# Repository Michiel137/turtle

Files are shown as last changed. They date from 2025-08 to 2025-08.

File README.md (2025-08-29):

# Turtle Robot

Een rijdende robot gemaakt met 3D prints, goedkope onderdelen en geprogrammeerd in MicroPython.

Alle bestanden, inclusief deze beschrijving zijn op GitHub te vinden: https://github.com/Michiel137/turtle

## Start

De robot bevat alle bestanden die je nodig hebt, maar hij moet nog wel geconfigureerd worden om hem via WiFi te kunnen programmeren.

1. Sluit de robot met een USB kabel aan op de computer
1. Installeer de ontwikkelomgiving voor MicroPython: [Thonny](https://thonny.org/).
1. Open Thonny. Kies "Standard" voor "Initial Settings"
1. Klik rechtsonderin de statusbalk om de interpreter te configureren
1. Kies "MicroPython (Raspberry Pi Pico)" voor de interpreter
1. Kies "Board in FS mode @ COM..." voor de poort
1. Onderin de shell zie je nu een Python prompt. Je kan hier Python commando's uitvoeren
1. Open in Thonny het bestand boot.py van de robot: Bestand -> Open -> Raspberry Pi Pico -> boot.py
1. Haal van de laatste regel in het bestand de "#" weg en vervang \<SSID\> en \<PASSWORD\> met de WiFi netwerknaam en het WiFi wachtwoord
1. Sla het bestand op: Bestand -> Opslaan
1. Herstart de robot door op het Stop icoon te klikken (of Uitvoeren -> Stoppen/Opnieuw starten backend)
1. De robot maakt nu verbinding met het WiFi netwerk
1. In het shell scherm wordt het adres van de robot geprint achter "WebREPL server started on". Kopieer dit adres
1. Klik rechtsonderin de statusbalk om de interpreter te configureren: Selecteer "Configureren interpreter"
1. Vul bij "Port or WebREPL" het adres van de robot in, maar vervang "http://" door "ws://"
1. Vul voor het wachtwoord "geheim" in
1. OK
1. Thonny maakt nu verbinding via WiFi. De USB kabel is niet meer nodig
1. Op de robot staan een aantal scripts die je uit kan proberen: Bestand -> Open -> Raspberry Pi Pico
    - blink.py - klipper met de leds
    - noise.py - maak geluid
    - collision.py - rij rond en probeer botsingen te voorkomen
    - square.py - teken een vierkant
1. Nadat je het script geopend hebt kan je het met F5 uitvoeren (of Uitvoeren -> Voer huidige script uit)
1. Sommige scripts hebben geen einde. Je kan het script stoppen met Ctrl-C (of Uitvoeren -> Onderbreek uitvoering)
1. Probeer de scripts uit en pas ze aan!
1. Als je een idee hebt en een nieuw script wil maken, maak dan een nieuw bestand: Bestand -> Nieuw
    - Bestanden hoeven niet op de robot te staan om ze uit te voeren: Bestand -> Opslaan -> Deze computer
    - Het is een goed idee om voor een nieuw script te beginnen met een kopie van een bestaand script
    - als je een fout in het script hebt gemaakt wordt dat in het shell scherm getoond als je het script uitvoerd

## Problemen Oplossen

1. Zijn de batterijen leeg?
1. Als de verbinding van Thonny met de robot niet meer lijkt te werken, verbind dan opnieuw door rechtonderin de statusbalk te klikken en "MicroPython (Raspberry Pi Pico) ws://\<ip\>:8266" te kiezen

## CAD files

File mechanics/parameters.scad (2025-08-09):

/// Default chamfer.
chamfer = 0.4;

/// Layer height used for printing.
layer = 0.2;

thickness_chassis = 2.4;
thickness_nut = 2.4;


//
// Wheel
//

/// Diameter of wheel (rim + tire).
// diameter_wheel = 56;  // OSTR V3
diameter_wheel = 50.5;  // OSTR V2
radius_wheel = diameter_wheel / 2;

/// Size of o-ring used as tire.
diameter_tire = 3;
radius_tire = diameter_tire / 2;


//
// Motor
//

diameter_motor = 28;
radius_motor = diameter_motor / 2;
spacing_motor_mounts = 35;
/// Mounting height of the motor from the top of the chassis plate.
height_motor = 13.1;
/// The axle is offset from the mounting holes of the motor.
height_axle = height_motor - 8;


//
// Pen (Stabilo 88/32)
//

diameter_pen = 7.75;
radius_pen = diameter_pen / 2;
tolerance_pen = 0.05;

/// The positions of the pen aligner mounting holes.
positions_aligner_mounts = [[-12.5 / 2, +8 / 2], [+12.5 / 2, -8 / 2]];


//
// Electronics
//

/// The radius of the board corners.
/// \note The back mounting hole is at the center of the rounding radius.
rounding_board = 4;
/// The width of the board (side-to-side).
width_board = 52;
/// The length of the board (back-to-front).
length_board = 48;
/// The side-to-side distance of the board mounts.
width_board_mounts = width_board - 2 * rounding_board;
/// The back-to-front distance of the board mounts.
/// \note The board mounts are at the back corner, but not at the front corner.
length_board_mounts = 33;
/// positions of the board mounts with the board anchored at the back
positions_board_mounts = [
    [+width_board_mounts / 2, -rounding_board],
    [+width_board_mounts / 2, -rounding_board - length_board_mounts],
    [-width_board_mounts / 2, -rounding_board - length_board_mounts],
];

width_battery_holder = 33;


//
// quality
//

$fa = $preview ? 12 : 3;
$fs = $preview ? 2 : 0.2;
$overlap = 0.01;

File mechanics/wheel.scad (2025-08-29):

include <BOSL2/std.scad>

include <parameters.scad>

width_rim = 4;
width_disc = 2.5;
width_hub = 9;
diameter_hub = 11;
radius_hub = diameter_hub / 2;
radius_rim = radius_wheel - radius_tire;

rounding_wheel = 1;

module wheel() {
    difference() {
        up(width_disc)
        union() {
            difference() {
                down(width_disc - width_rim / 2)
                difference() {
                    cyl(r=radius_rim, h=width_rim, chamfer=chamfer);
                    // tire recess
                    torus(or=radius_wheel, r_min=radius_tire);
                }

                // disc
                radius_disc = radius_rim - 2 - 2 * chamfer;
                cyl(r=radius_disc, h=width_rim - width_disc, rounding1=rounding_wheel, chamfer2=-chamfer, extra2=$overlap, anchor=BOTTOM);

                // disc holes
                diameter_hole = radius_disc - radius_hub - 4 * rounding_wheel;
                radius_hole = diameter_hole / 2;
                zrot_copies(n=5)
                back((radius_disc + radius_hub) / 2)
                cyl(r=radius_hole, h=width_disc, rounding=-rounding_wheel, extra=$overlap, anchor=TOP);
            }

            // hub
            cyl(r=radius_hub, h=width_hub - width_disc, rounding1=-rounding_wheel, rounding2=rounding_wheel, extra1=$overlap, anchor=BOTTOM);
        }

        // shaft
        path = intersection([circle(d=5), rect([3, 10])])[0];
        offset_sweep(path, h=width_hub, ends=os_chamfer(-chamfer, extra=$overlap), anchor=BOTTOM);
        // shaft M3 set screw (only one has to be used)
        up(width_hub - 3)
        cyl(d=2.8, h=diameter_hub, chamfer=-chamfer, orient=RIGHT);
    }
}

module tire() {
    up(width_rim / 2)
    torus(or=radius_wheel, r_min=radius_tire);
}

wheel();
// color("grey")
// tire();

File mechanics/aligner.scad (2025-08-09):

/// \file
/// Screw-on piece to accurately align the pen at the bottom.

use <components.scad>

include <BOSL2/std.scad>
include <BOSL2/screws.scad>

include <parameters.scad>

height = 10;

module aligner_stabilo() {
    // the aligner is mounted up side down
    xflip()
    difference () {
        union() {
            offset_sweep(rect([18, 12], rounding=2.4), h=3, ends=os_chamfer(chamfer));

            difference() {
                cyl(d=12, h=height, chamfer=chamfer, anchor=BOTTOM);

                for (position = positions_aligner_mounts) {
                    move(position)
                    cyl(d=4, h=height, chamfer=-chamfer, extra=$overlap, anchor=BOTTOM);
                }
            }
        }

        pen_stabilo(height);

        for (position = positions_aligner_mounts) {
            move(position)
            // M2 screw
            cyl(d=2.2, l=10);
        }
    }
}

aligner_stabilo();

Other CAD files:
mechanics/caster.scad
mechanics/chassis.scad
mechanics/collar.scad
mechanics/components.scad

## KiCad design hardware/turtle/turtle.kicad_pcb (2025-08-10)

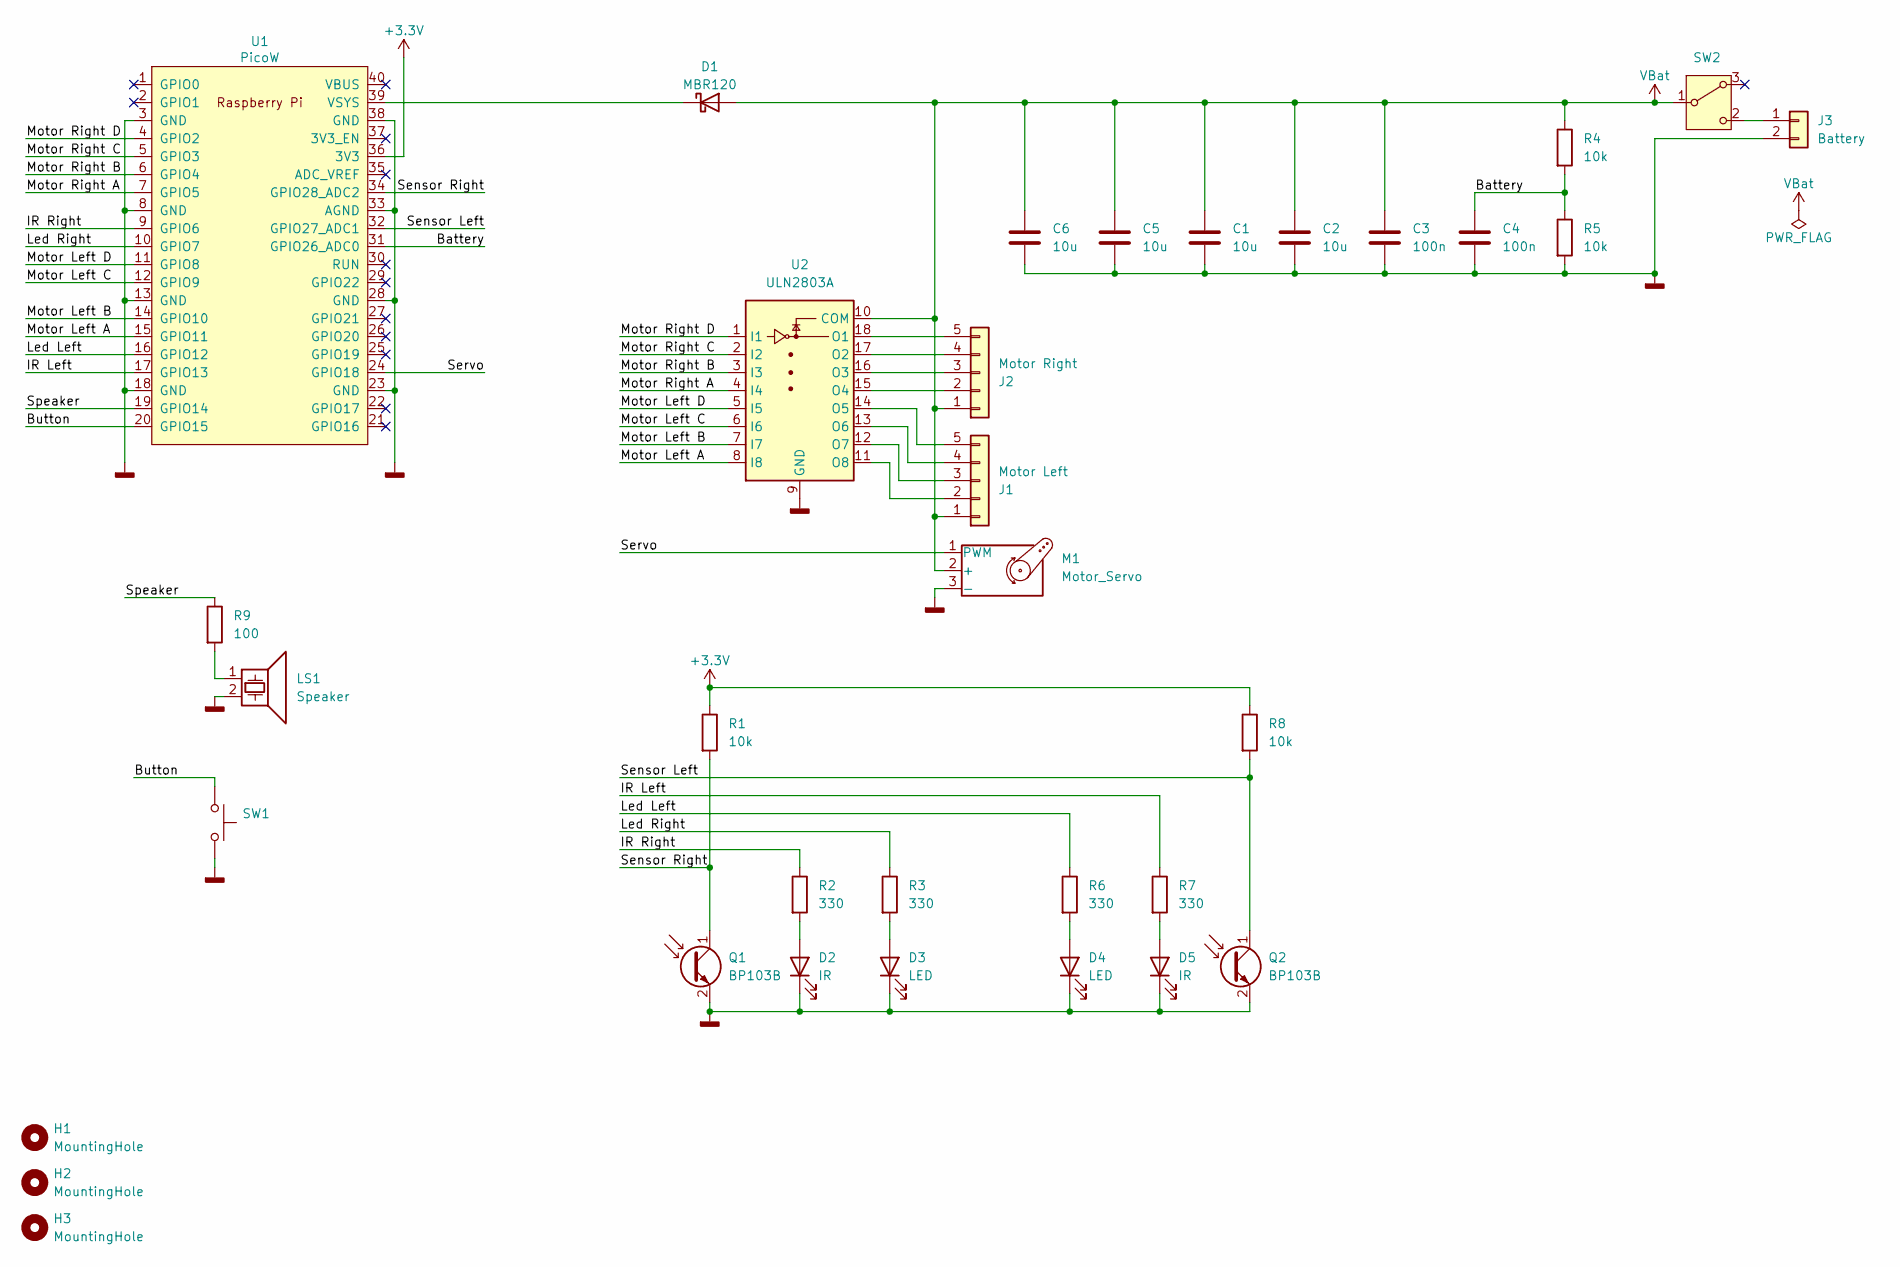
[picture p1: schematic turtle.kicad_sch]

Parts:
C1, C2, C5, C6: 10u; C_0603_1608Metric_Pad1.08x0.95mm_HandSolder
C3, C4: 100n; C_0603_1608Metric_Pad1.08x0.95mm_HandSolder
D1: MBR120; D_SOD-123F
D2, D5: IR; LED_D5.0mm_Horizontal_O1.27mm_Z3.0mm_truncated_silkscreen
D3, D4: LED; LED_D5.0mm_Horizontal_O1.27mm_Z3.0mm_truncated_silkscreen
H1, H2, H3: MountingHole; MountingHole_2.2mm_M2
J1: Motor Left; JST_EH_B5B-EH-A_1x05_P2.50mm_Vertical
J2: Motor Right; JST_EH_B5B-EH-A_1x05_P2.50mm_Vertical
J3: Battery; JST_EH_B2B-EH-A_1x02_P2.50mm_Vertical
LS1: Speaker; Buzzer_TDK_PS1240P02BT_D12.2mm_H6.5mm
M1: Motor_Servo; PinHeader_1x03_P2.54mm_Vertical
Q1, Q2: BP103B; LED_D5.0mm_Horizontal_O1.27mm_Z3.0mm_truncated_silkscreen
R1, R4, R5, R8: 10k; R_0603_1608Metric_Pad0.98x0.95mm_HandSolder
R2, R3, R6, R7: 330; R_0603_1608Metric_Pad0.98x0.95mm_HandSolder
R9: 100; R_0603_1608Metric_Pad0.98x0.95mm_HandSolder
SW1: SW_Push; SW_Push_1P1T_NO_CK_KSC6xxJ
SW2: SW_Wuerth_450301014042; SW_Slide-03_Wuerth-WS-SLTV_10x2.5x6.4_P2.54mm
U1: PicoW; RaspberryPi_Pico_Common_THT_stacked
U2: ULN2803A; SOIC-18W_7.5x11.6mm_P1.27mm

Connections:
+3.3V: R1.1, R8.1, U1.36 (3V3)
/Battery: C4.1, R4.2, R5.1, U1.31 (GPIO26_ADC0)
/Button: SW1.1, U1.20 (GPIO15)
/IR Left: R7.1, U1.17 (GPIO13)
/IR Right: R2.1, U1.9 (GPIO6)
/Led Left: R6.1, U1.16 (GPIO12)
/Led Right: R3.1, U1.10 (GPIO7)
/Motor Left A: U1.15 (GPIO11), U2.8 (I8)
/Motor Left B: U1.14 (GPIO10), U2.7 (I7)
/Motor Left C: U1.12 (GPIO9), U2.6 (I6)
/Motor Left D: U1.11 (GPIO8), U2.5 (I5)
/Motor Right A: U1.7 (GPIO5), U2.4 (I4)
/Motor Right B: U1.6 (GPIO4), U2.3 (I3)
/Motor Right C: U1.5 (GPIO3), U2.2 (I2)
/Motor Right D: U1.4 (GPIO2), U2.1 (I1)
/Sensor Left: Q2.1 (C), R8.2, U1.32 (GPIO27_ADC1)
/Sensor Right: Q1.1 (C), R1.2, U1.34 (GPIO28_ADC2)
/Servo: M1.1 (PWM), U1.24 (GPIO18)
/Speaker: R9.1, U1.19 (GPIO14)
GNDD: C1.2, C2.2, C3.2, C4.2, C5.2, C6.2, D2.1 (K), D3.1 (K), D4.1 (K), D5.1 (K), J3.2, LS1.2, M1.3 (-), Q1.2 (E), Q2.2 (E), R5.2, SW1.2, U1.3 (GND), U1.8 (GND), U1.13 (GND), U1.18 (GND), U1.23 (GND), U1.28 (GND), U1.33 (AGND), U1.38 (GND), U2.9 (GND)
unnamed: D1.1 (K), U1.39 (VSYS)
unnamed: D2.2 (A), R2.2
unnamed: D3.2 (A), R3.2
unnamed: D4.2 (A), R6.2
unnamed: D5.2 (A), R7.2
unnamed: J1.2, U2.11 (O8)
unnamed: J1.3, U2.12 (O7)
unnamed: J1.4, U2.13 (O6)
unnamed: J1.5, U2.14 (O5)
unnamed: J2.2, U2.15 (O4)
unnamed: J2.3, U2.16 (O3)
unnamed: J2.4, U2.17 (O2)
unnamed: J2.5, U2.18 (O1)
unnamed: J3.1, SW2.2 (C)
unnamed: LS1.1, R9.2
VBat: C1.1, C2.1, C3.1, C5.1, C6.1, D1.2 (A), J1.1, J2.1, M1.2 (+), R4.1, SW2.1 (B), U2.10 (COM)

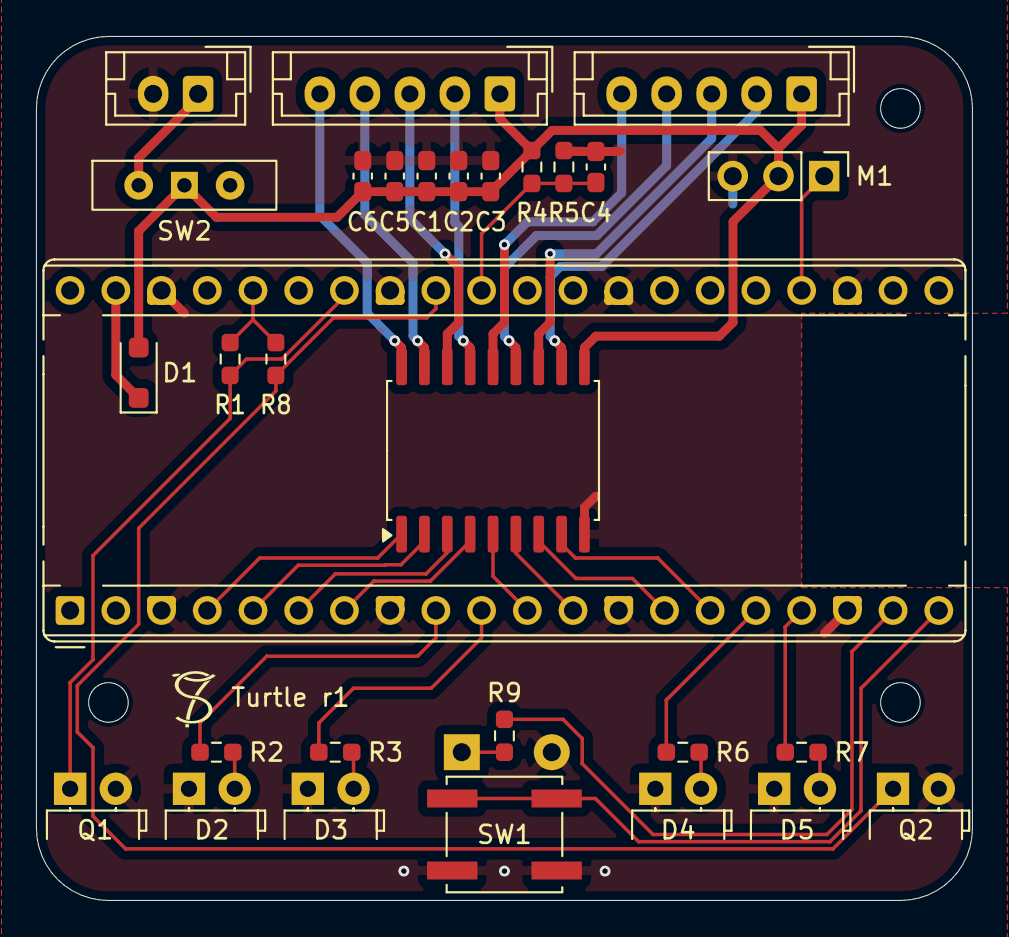
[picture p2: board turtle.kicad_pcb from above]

Board: 2 copper layers, 52.0 x 48.0 mm, 34 parts (1 on the bottom side), 36 nets.

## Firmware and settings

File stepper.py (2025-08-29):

from machine import Pin, Timer


class Stepper:
    ''' Control a unipolar stepper motor like the 28BYJ-48 via a driver like
        the ULN2003 directly connected to 4 microcontroller GPIO pins.
    '''

    FORWARD = 1
    BACK = -1

    def __init__(self, pin_ids):
        ''' Initialize the stepper.
            :param int pin_ids: The ids of the 4 control pins connected the inputs of the driver IC
        '''
        self._pins = [Pin(pin_ids[i], mode=Pin.OUT, value=0) for i in range(4)]
        # wave steps: only on coil is active at a time
        #self._step_sequence = [[1, 0, 0, 0], [0, 1, 0, 0], [0, 0, 1, 0], [0, 0, 0, 1]]
        # full steps: two coils are active at a time
        self._step_sequence = [[1, 1, 0, 0], [0, 1, 1, 0], [0, 0, 1, 1], [1, 0, 0, 1]]
        self._step_index = 0
        self._timer = Timer()
        self._moving = False

    @property
    def is_moving(self):
        ''' Return whether the stepper is moving.
        '''
        return self._moving

    def move(self, direction, speed, count=None):
        ''' Move the stepper motor.

            :param int direction: The direction (Stepper.FORWARD=1 or Stepper.BACK=-1) to move in
            :param int speed: Number of steps per second
            :param int count: The number of steps, or None to run continuously
        '''
        self.stop()
        self._step_direction = int(direction)
        self._step_count = None if count is None else int(count)
        self._timer.init(mode=Timer.PERIODIC, freq=speed, callback=self._update)
        self._moving = True

    def stop(self):
        ''' Stop moving the stepper.
        '''
        self._timer.deinit()
        self._moving = False

    def deactivate(self):
        ''' Stop moving the stepper and deactivate it.
        '''
        self.stop()
        for pin_index in range(len(self._pins)):
            self._pins[pin_index].value(0)

    def _step(self):
        ''' Make a single step in the set direction.
        '''
        self._step_index = (self._step_index + self._step_direction) % len(self._step_sequence)
        for pin_index in range(len(self._pins)):
            self._pins[pin_index].value(self._step_sequence[self._step_index][pin_index])

    def _update(self, _):
        ''' Timer callback.
        '''
        if self._step_count is None:
            self._step()
        elif self._step_count > 0:
            self._step()
            self._step_count -= 1
        else:
            self._moving = False


if __name__ == '__main__':
    from time import sleep
    # motor = Stepper([5, 4, 3, 2])  # left motor
    motor = Stepper([11, 10, 9, 8])  # right motor
    motor.move(1, 500, 2048)

    while motor.is_moving:
        sleep(0.1)

    motor.deactivate()

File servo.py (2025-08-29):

from machine import Pin, PWM


class Servo():
    ''' Control position of a hobby servo motor via a PWM capable GPIO pin.
    '''

    def __init__(self, pin_id, position=None):
        ''' Initialize the servo and sets its initial position.

            :param int pin_id: The id of the PWM capable pin attached to the control input of the servo
            :param float position: The control value [0.0 .. 1.0] for the initial position. If None, deactives the servo
        '''
        pin = Pin(pin_id, Pin.OUT)
        self._pwm = PWM(pin, freq=50, duty_u16=self.duty_cycle(position))

    def position(self, value):
        ''' Set the servo position.
            :param float value: The control value [0.0 .. 1.0] for the new position
        '''
        self._pwm.duty_u16(self.duty_cycle(value))

    def deactivate(self):
        ''' Deactivate the servo.
            It will probably keep its position because of friction, but it will not actively maintain it.
        '''
        self._pwm.duty_u16(0)

    @staticmethod
    def duty_cycle(control):
        ''' Convert control value [0.0 .. 1.0] to PWM duty cycle.
        '''
        return int((1 / 20 + 1 / 20 * control) * 65535)

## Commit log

2025-08-03 Add mechanical parts.
    [caster.scad, chassis.scad, wheel.scad]
2025-08-03 Add design for electronics.
    [turtle.kicad_pcb, turtle.kicad_sch]
2025-08-03 Update chassis for new board size.
    [chassis.scad]
2025-08-09 Split off parameters and add different components.
    [aligner.scad, caster.scad, chassis.scad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]
2025-08-10 Update for ordered components.
    ULN2803A instead of ULN2803C.
    Speaker with 5mm pitch.
    [turtle.kicad_pcb, turtle.kicad_sch]
2025-08-10 Add logo and revision to PCB.
    [turtle.kicad_pcb]
2025-08-10 Add revision 1 PCB submitted to JCLPCB for fabrication.
2025-08-27 Move mounting flange of caster to one side.
    This makes room for the battery holder, no matter how large the ball is.
    [caster.scad]
2025-08-28 Make the back side of the collar square.
    This gives a better platform for the servo to push against.
    [collar.scad]
2025-08-29 Make the embedded nuts a slightly tighter fit.
    [chassis.scad, wheel.scad]
2025-08-29 Move mechanics design into separate directory.
    [aligner.scad, caster.scad, chassis.scad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]
